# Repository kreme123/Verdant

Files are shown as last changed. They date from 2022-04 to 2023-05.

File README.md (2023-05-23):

# Verdant

Verdant is ISO 40% keyboard with OLED and rotary encoder.
- Uses Pro Micro and THT diodes
- Pcb gasket mount
- O-ring gaskets
- Plateless
- Stacked acrylic case
- Rgb underglow

### Proto
<a href="https://imgur.com/1ZLlh2G">source: imgur.com</a>
<a href="https://imgur.com/oCUwPO0">source: imgur.com</a>
<a href="https://imgur.com/XJFyLRA">source: imgur.com</a>
<a href="https://imgur.com/ZebSnNk">source: imgur.com</a>
### Sound test
https://user-images.githubusercontent.com/85822364/162204149-778293da-0471-405d-8712-a8b8ee973648.mp4
### Renders
<a href="https://imgur.com/0ZNS8gC">source: imgur.com</a>
### Pcb
<a href="https://imgur.com/nBw0oRB">source: imgur.com</a>
### KLE
<a href="https://imgur.com/f6jKrXc">source: imgur.com</a>
> View on [Keyboard Layout Editor](http://www.keyboard-layout-editor.com/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'&=~%0A%23%3B&@=Shift&=%7C%0A%5C&=Z&=X&=C&=V&=B&=N&=M&=%3C%0A,&=%3E%0A.&=%3F%0A%2F%2F&_w:1.25%3B&=Layer&_w:1.25%3B&=Shift%3B&@_w:1.25%3B&=Ctrl&=Layer&_w:1.25%3B&=Alt&_a:7&w:7%3B&=&_a:4%3B&=%E2%86%90&=%E2%86%93&=%E2%86%91&=%E2%86%92%3B&@_y:0.25&a:7&w:1.25%3B&=&=&=&=&_w:6.25%3B&=)

(https://www.paypal.com/donate/?hosted_button_id=BAEE2KMJAVYBW)

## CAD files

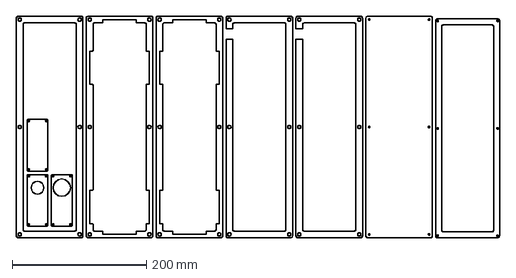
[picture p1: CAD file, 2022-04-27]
Case/Case all.dxf
720.0 x 330.1 mm

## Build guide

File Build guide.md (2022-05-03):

# Build guide

## Materials
- 20 x [M2x8mm screws](https://www.aliexpress.com/item/32870342767.html?spm=a2g0s.9042311.0.0.52114c4dn6suyl)
- 10 x [M2x14mm standoffs](https://www.aliexpress.com/item/1005001478301407.html?spm=a2g0s.9042311.0.0.52114c4dn6suyl)
- ~50 [1N4148 diodes](https://www.aliexpress.com/item/2025724181.html?spm=a2g0s.9042311.0.0.52114c4d259Ayp)
- 6 x [32mm (OD) x 2.4mm O-rings](https://www.aliexpress.com/item/32908087735.html?spm=a2g0o.order_list.0.0.60cf1802kyAhZY)
- [OLED](https://www.aliexpress.com/item/32896971385.html?spm=a2g0o.order_list.0.0.4c291802RJLFPs)
- [EC11 rotary encoder](https://www.aliexpress.com/item/10000056483250.html?spm=a2g0s.9042311.0.0.52114c4dn6suyl)
- [Encoder knob](https://www.aliexpress.com/item/1005002683252060.html?spm=a2g0o.order_list.0.0.5b901802I6F5Fy)
- [Silicone rubber feet](https://www.aliexpress.com/item/4000439059508.html?spm=a2g0s.9042311.0.0.52114c4dn6suyl)
- [Aluminum feet](https://www.aliexpress.com/item/32947889825.html?spm=a2g0s.9042311.0.0.52114c4dn6suyl)
- [WS2812B led strip](https://www.aliexpress.com/item/32682015405.html?spm=a2g0s.9042311.0.0.52114c4dn6suyl) 60 IP30 (17 leds on one Verdant) 
- [Double sided tape for feet](https://www.aliexpress.com/item/1005001401843627.html?spm=a2g0s.9042311.0.0.52114c4dn6suyl) round 20mm
- [Pro Micro](https://www.aliexpress.com/item/32768308647.html?spm=a2g0o.productlist.0.0.20f5f2022mgoaF)

### Also
- Soldering iron and solder
- Phillips screwdriver
- Flush side cutters
- ~50 MX style switches
- 7u/6.25u and 2u PCB mount stabilizers
- Keycaps (check compatibility)

## Building

Connect Pro Micro to computer and flash "verdant_default.hex" firmware using qmk toolbox

Solder diodes for all keys. Black stripe on diode to square pad on pcb
<a href="https://imgur.com/B3Za0va">source: imgur.com</a>

If you want to use encoder, solder jump wires from Pro Micro to PCB
https://golem.hu/guide/pro-micro-upgrade/
<a href="https://imgur.com/1B2dL1g">source: imgur.com</a>

Solder Pro Micro to top side of pcb. Check that pins match. Cut off the excess legs. 
I suggest wearing eye protection and placing something to top of Pro Micro when cutting excess legs. Those legs will fly.
<a href="https://imgur.com/q71w0Xe">source: imgur.com</a>

Add rotary encoder (optional)

Add OLED to top of Pro Micro. Use something like electrical tape between back of oled and top of pro micro to avoid unwanted connection.
<a href="https://imgur.com/kMMEzFK">source: imgur.com</a>

Solder switches and add stabilizers.

Solder rgb strip (optional). Check that strip is correct way (din on strip matches din text on pcb). 
Add soldering iron to rgb strip pins and holes at pcb. Place them closely and heat up to connect them
<a href="https://imgur.com/yCE28Dx">source: imgur.com</a>

Add acrylic cover to pcb using screws and standoffs.

Add O-ring gaskets
<a href="https://imgur.com/FsS0UGJ">source: imgur.com</a>

## Case

Put screws from the bottom and add standoffs. 

Add legs.

Add case layers 2-4

Add soldered pcb.

Add rest of the case layers 5-7 and screw it in.

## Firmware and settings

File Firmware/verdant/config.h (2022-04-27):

/* Copyright 2022 Kreme
 *
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
 * You should have received a copy of the GNU General Public License
 * along with this program.  If not, see <http://www.gnu.org/licenses/>.
 */

#pragma once

#include "config_common.h"

 /* USB Device descriptor parameter */
#define VENDOR_ID       0xFEED
#define PRODUCT_ID      0x0000
#define DEVICE_VER      0x0001
#define MANUFACTURER    Kreme
#define PRODUCT         Verdant

/* key matrix size */
#define MATRIX_ROWS 8
#define MATRIX_COLS 7

/*
 * Keyboard Matrix Assignments
 *
 * Change this to how you wired your keyboard
 * COLS: AVR pins used for columns, left to right
 * ROWS: AVR pins used for rows, top to bottom
 * DIODE_DIRECTION: COL2ROW = COL = Anode (+), ROW = Cathode (-, marked on diode)
 *                  ROW2COL = ROW = Anode (+), COL = Cathode (-, marked on diode)
 *
 */
#define MATRIX_ROW_PINS { D2, B4, F7, D7, D4, E6, B3, B1 }
#define MATRIX_COL_PINS { C6, F6, B5, D3, B6, F4, F5 }

#define DIODE_DIRECTION COL2ROW

#define ENCODERS_PAD_A \
    { B0 }
#define ENCODERS_PAD_B \
    { D5 }
#define ENCODER_RESOLUTION 4
#define ENCODER_DIRECTION_FLIP
#define TAP_CODE_DELAY 10

#define OLED_TIMEOUT 120000
#define OLED_BRIGHTNESS 120

#define NO_ACTION_MACRO
#define NO_ACTION_FUNCTION

#define RGB_DI_PIN B2
#ifdef RGB_DI_PIN
#define RGBLED_NUM 17
#define RGBLIGHT_HUE_STEP 8
#define RGBLIGHT_SAT_STEP 8
#define RGBLIGHT_VAL_STEP 8
#define RGBLIGHT_LIMIT_VAL 255 /* The maximum brightness level */
#define RGBLIGHT_SLEEP  /* If defined, the RGB lighting will be switched off when the host goes to sleep */
 /*== all animations enable ==*/
#define RGBLIGHT_ANIMATIONS
// /*== or choose animations ==*/
//     #define RGBLIGHT_EFFECT_BREATHING
//     #define RGBLIGHT_EFFECT_RAINBOW_MOOD
//     #define RGBLIGHT_EFFECT_RAINBOW_SWIRL
//     #define RGBLIGHT_EFFECT_SNAKE
//     #define RGBLIGHT_EFFECT_KNIGHT
//     #define RGBLIGHT_EFFECT_CHRISTMAS
//     #define RGBLIGHT_EFFECT_STATIC_GRADIENT
//     #define RGBLIGHT_EFFECT_RGB_TEST
//     #define RGBLIGHT_EFFECT_ALTERNATING
#endif

// generated by KBFirmware JSON to QMK Parser
// https://noroadsleft.github.io/kbf_qmk_converter/

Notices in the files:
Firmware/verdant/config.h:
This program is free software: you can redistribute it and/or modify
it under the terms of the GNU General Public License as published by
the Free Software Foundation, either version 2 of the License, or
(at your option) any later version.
